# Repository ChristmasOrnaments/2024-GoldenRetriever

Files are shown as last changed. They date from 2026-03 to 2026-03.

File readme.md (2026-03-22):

Christmas ornament number 12...

***

The detailed explanation of the original Snowman ornament is [here](https://github.com/ChristmasOrnaments/2013-Snowman).

This ornament shares the same schematic and code base as the previous ornaments. Obviously the silkscreen image and LED locations have changed.  

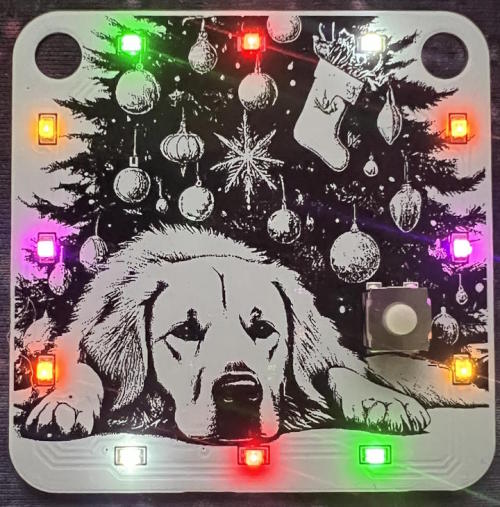
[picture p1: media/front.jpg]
front

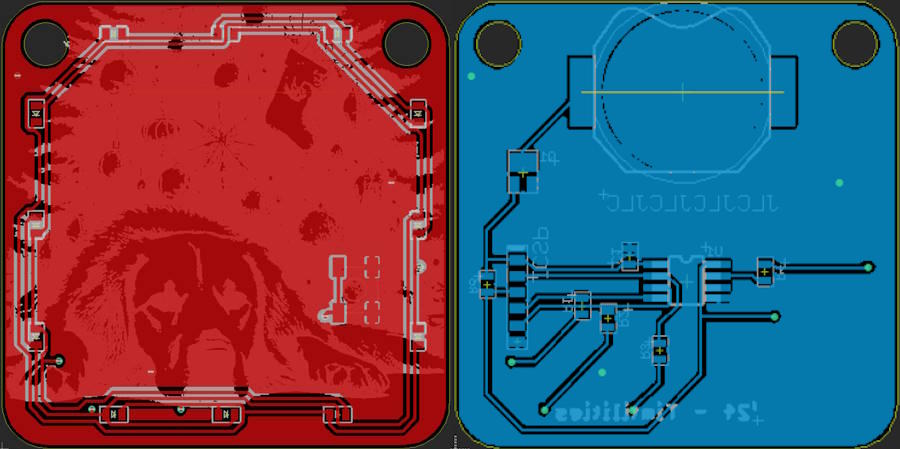
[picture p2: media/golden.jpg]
goldenretriever

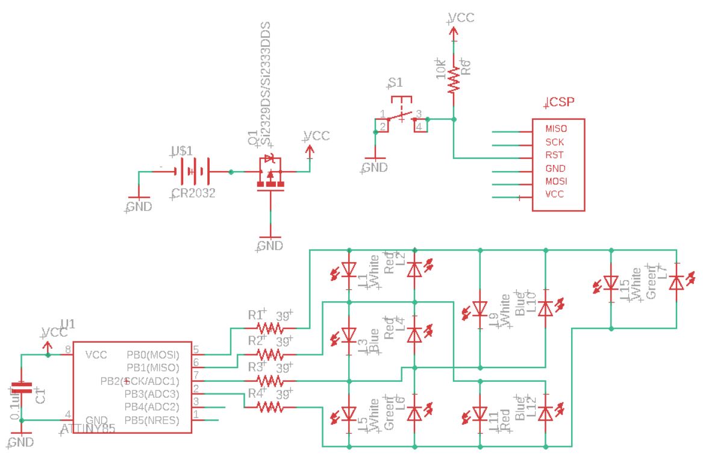
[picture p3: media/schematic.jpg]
schematic

GoldenRetriever

### Compiling

* Install [ATTinyCore](https://github.com/spencekonde/attinycore) using the boards manager
* Select **Attiny25/45/85 (No bootloader)** from the boards list
* Set the *Clock source* to **8MHz (internal)** (Code uses a prescalar of 2 to lower it to 4MHz)
* Set *B.O.D* to **Disabled**
* Select **Burn Bootloader** to write the changes
* Compile and write the program to the MCU

If using another method to program the MCU, just remember you need to set the fuses properly both for correct speed and for the power saving features. The fuses (for an ATTINY85) should be:

Low: 62  
High: DF  
Extended: FF

You can see the effect of different fuse settings (and their values) [here](http://www.engbedded.com/fusecalc/).

### Resources

**Charlieplexing Code using a byte array:**  
[https://www.instructables.com/CharliePlexed-LED-string-for-the-Arduino/](https://www.instructables.com/CharliePlexed-LED-string-for-the-Arduino/)

**Battery calculator:**  
[http://oregonembedded.com/batterycalc.htm](http://oregonembedded.com/batterycalc.htm)

**Power saving information:**  
[http://www.gammon.com.au/forum/?id=11497](http://www.gammon.com.au/forum/?id=11497)  
[http://www.insidegadgets.com/2011/02/05/reduce-attiny-power-consumption-by-sleeping-with-the-watchdog-timer](http://www.insidegadgets.com/2011/02/05/reduce-attiny-power-consumption-by-sleeping-with-the-watchdog-timer/)  
[http://www.nongnu.org/avr-libc/user-manual/group\_\_avr\_\_power.html](http://www.nongnu.org/avr-libc/user-manual/group__avr__power.html)

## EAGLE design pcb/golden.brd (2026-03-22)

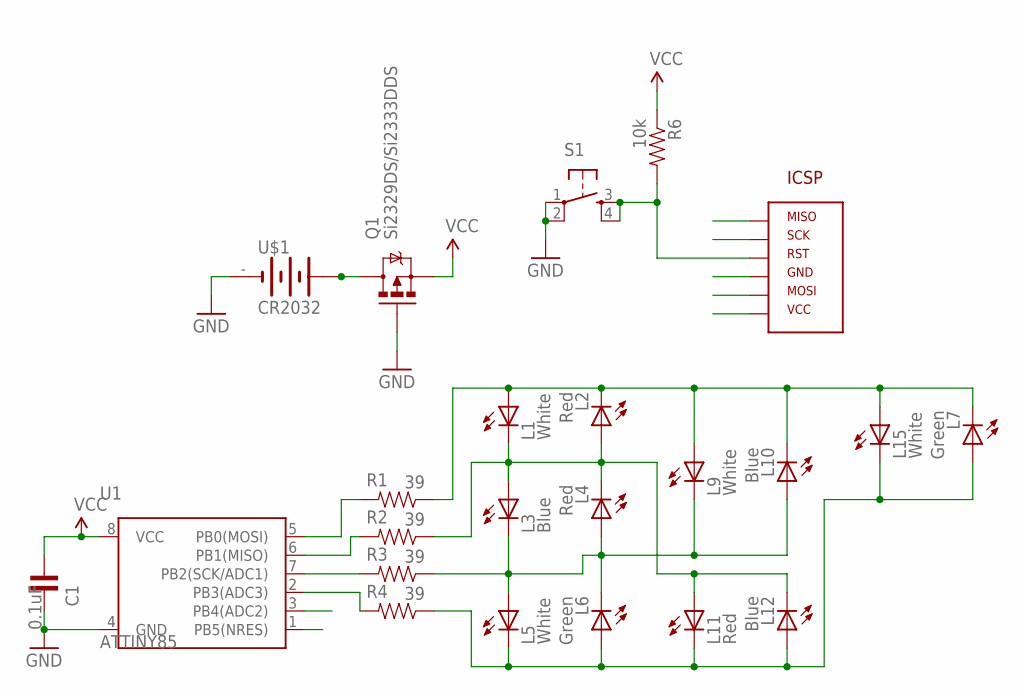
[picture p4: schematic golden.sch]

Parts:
C1: 0.1uF; C0805
L1, L5, L9, L15: White; LED-0805
L2, L4, L11: Red; LED-0805
L3, L10, L12: Blue; LED-0805
L6, L7: Green; LED-0805
Q1: Si2329DS/Si2333DDS; SOT23-3A
R1, R2, R3, R4: 39; R0805
R6: 10k; R0805
S1: TAC_SWITCHSMD; TACTILE_SWITCH_SMD
U1: ATTINY85; SOIC-8
U$1: CR2032; BAT-HLD-001
U$2: AVR_ICSP_6P1X6; AVR_ICSP_1X6_SMD

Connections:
GND: C1.2, Q1.1 (G), S1.1, S1.2, U1.4 (GND), U$1.-, U$2.P6 (GND)
L12: L1.C, L2.A, L3.A, L4.C, L11.A, L12.C, R2.1
MISO: R2.2, U1.6 (PB1(MISO)), U$2.P5 (MISO)
MOSI: R1.2, U1.5 (PB0(MOSI)), U$2.P4 (MOSI)
unnamed: Q1.3 (D), U$1.+@1 (+), U$1.+@2 (+)
unnamed: L3.C, L4.A, L5.A, L6.C, L9.C, L10.A, R3.1
unnamed: R4.2, U1.2 (PB3(ADC3))
unnamed: L1.A, L2.C, L7.C, L9.A, L10.C, L15.A, R1.1
unnamed: L5.C, L6.A, L7.A, L11.C, L12.A, L15.C, R4.1
RST: R6.2, S1.3, S1.4, U1.1 (PB5(NRES)), U$2.P3 (RST)
SCK: R3.2, U1.7 (PB2(SCK/ADC1)), U$2.P2 (SCK)
VCC: C1.1, Q1.2 (S), R6.1, U1.8 (VCC), U$2.P1 (VCC)

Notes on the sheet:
ICSP

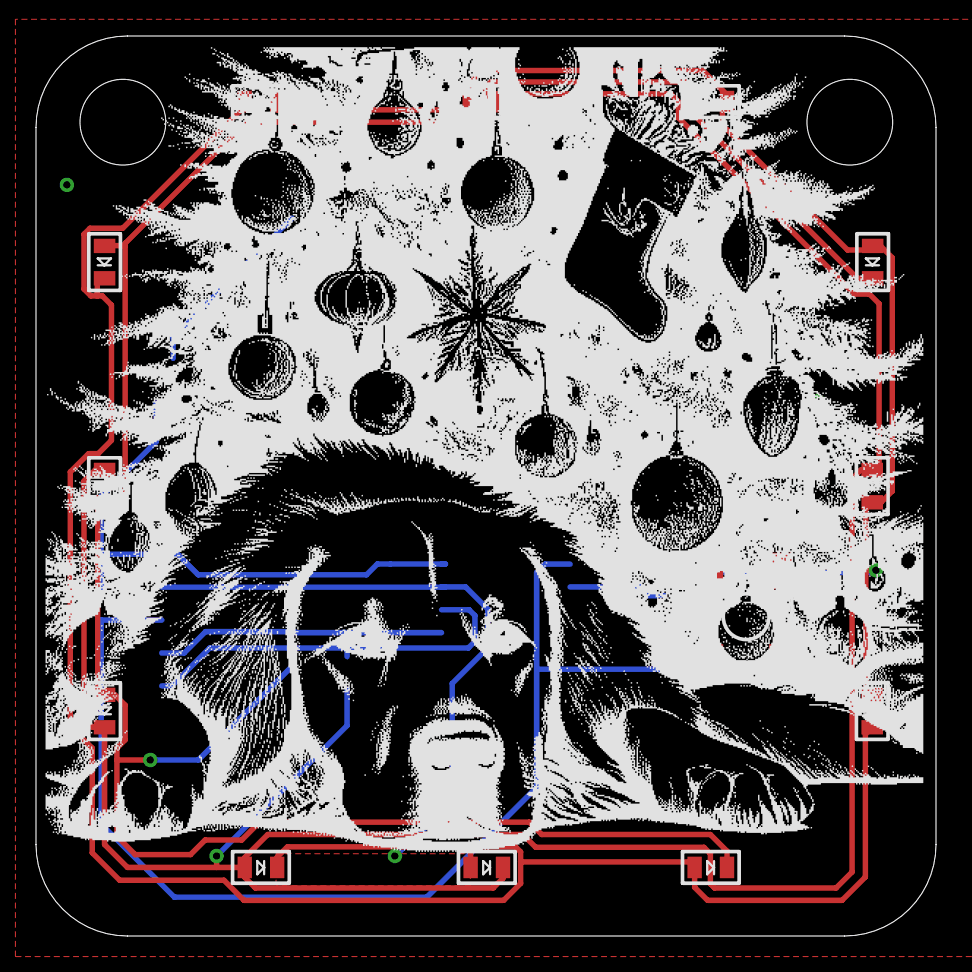
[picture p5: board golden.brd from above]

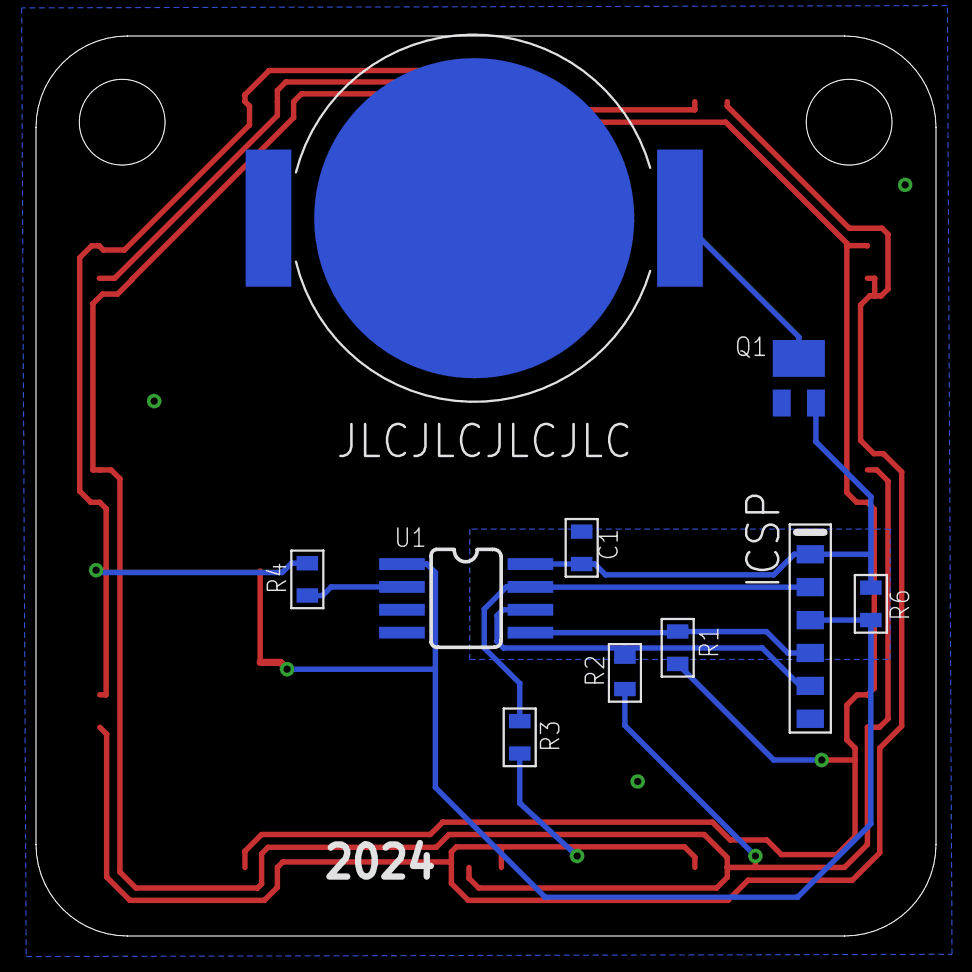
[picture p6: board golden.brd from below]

Board: 2 copper layers, 50.0 x 50.0 mm, 23 parts (10 on the bottom side), 12 nets.

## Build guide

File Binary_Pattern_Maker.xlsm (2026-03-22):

 |  |  |  |  |  |  | Not Used
 |  |  | 0 | 0 | 0
 | 0 |  |  |  |  | 0
 | 0 |  |  |  |  | 0
 | 0 |  |  |  |  | 0
 |  |  | 0 | 0 | 0
9-LED Array: |  | 0,0,0,0,0,0,0,0,0
12-LED Array: |  | 0,0,0,0,0,0,0,0,0,0,0,0

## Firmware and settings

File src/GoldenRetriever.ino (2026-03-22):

/*
 * ATTiny85_Internal_8MHz_Template.cpp
 *
 * Created: 11/5/2024
 * Charlieplexing functions modeled after the code found here:
 *  http://www.instructables.com/id/CharliePlexed-LED-string-for-the-Arduino/step7/Coding-the-Arduino/
 * 2019 - Added prescalar of 2 to accomodate 8MHz clock div/8 (low fuse 0x62)
 */ 

#ifdef F_CPU  
#undef F_CPU
#endif	
#define F_CPU 4000000 // 4 MHz

// ATMEL ATTINY85 / ARDUINO
//	            						  ____
//  		   (D5/A0) RST/PB5	1|*	  |8  VCC
//	 PWM   (D3/A3)	   PB3	2|	  |7  PB2  (D2/A1)
//	 PWM   (D4/A2)	   PB4	3|	  |6  PB1  (D1)		PWM
//	        				   GND	4|____|5  PB0  (D0)		PWM

#include <avr/pgmspace.h>
// Power Mgt:
#include <avr/sleep.h>
#include <avr/wdt.h>

// FUNCTION PROTOTYPES
void displayChar(int from, int through, int tranSpeed); // loads a Pattern from above. From & through specify what patterns to show. tranSpeed is the speed of the frames
//void ledSpecify(int highPin, int lowPin); // This allows you to manually control which pin goes low & which one goes high
void turnon(int led); // This turns on a certian led from the list of leds
void alloff(); // This turns all the LED's off
void setup_watchdog(int ii);
void system_sleep();

// ******************************************************************************************************************
//
// Much of the charlieplex code has been modified from http://www.instructables.com/id/CharliePlexed-LED-string-for-the-Arduino/step7/Coding-the-Arduino/
// The power management code is from 

#define LEDCount 12
byte pins[4];
//const byte LEDCount = 20;

// The attiny85 watchdog only sleeps for 8 seconds at a time, so for a longer period of time we need to setup a counter variable
//	 and check that against the # of times it wakes up.
// The internal clock isn't very accurate, so you need to factor that in. My tests show a deviation of ~0.9198 at 900 seconds,
//	 so a rough equation would be [ SleepTime = DesiredTime * 0.9198 ]
// Every MCU will be different, so some experimentation will be necessary if you want accurate intervals
// Some example times:
//	 5:00 -> 276
//	10:00 -> 552
//	15:00 -> 828
//	30:00 -> 1656
int SleepTime = 416; // Sleep time in seconds

int SleepCnt = SleepTime/8; // counter for watchdog wake timer

// blinkdelay is used by displayChar to set the microseconds the LED will be on, then off. It can affect brightness, but mostly affects speed
// blinkdelay could be replaced with a timeOn and timeOff to facilitate a type of PWM to increase LED brightness at low voltage 
//		(using a small Rs at higher voltage would be bad for LED unless turn-on time can be limited with this)
int blinkdelay = 90;   //Speed Param 1: smaller = faster
// runSpeed is the number of times displayChar will loop through each pattern before going to the next. Again, this affects speed
byte runSpeed = 90;		 //Speed Param 2: smaller = faster (0-255) - this can be set individually when calling displayChar()

// Random number
int RndNumber = 0;

#ifndef cbi
#define cbi(sfr, bit) (_SFR_BYTE(sfr) &= ~_BV(bit))
#endif
#ifndef sbi
#define sbi(sfr, bit) (_SFR_BYTE(sfr) |= _BV(bit))
#endif
volatile boolean f_wdt = 1;

const byte LEDConnections[LEDCount][2] ={	// This stores which outputs the LEDs are connected to: { Anode, Cathode }
	// Bottom Row
	{ 0 , 1 },	  //X1
	{ 1 , 2 },	  //X3
	{ 2 , 3 },	  //X5
	// Row 1
	{ 1 , 0 },	  //X2			  
	{ 2 , 1 },	  //X4
	{ 3 , 2 },	  //X6
	// Row 2
	{ 0 , 2 },	  //X9
	{ 1 , 3 },	  //X11
	// Row 3
	{ 2 , 0 },	  //X10
	{ 3 , 1 },	  //X12
	// Row 4
	{ 0 , 3 },	  //X15
	{ 3 , 0 }	  //X7
};

const byte displays[][LEDCount] PROGMEM ={	// This stores the array in Flash ROM.
	// All Off (0)
	{0,0,0,0,0,0,0,0,0,0,0,0},

	// Pattern 1: All LEDs Flash (1-2)
	{1,1,1,1,1,1,1,1,1,1,1,1},
	{0,0,0,0,0,0,0,0,0,0,0,0},

	// Pattern 2: 3 LED Race Clockwise (3-28)
	{ 0,0,1,0,0,0,0,0,0,0,0,0 }, //  3 x
	{ 0,0,1,0,0,0,0,0,0,1,0,0 }, //  4 xx
	{ 0,0,1,0,0,0,0,0,0,1,1,0 }, //  5 xxx
	{ 0,0,0,0,0,0,0,0,0,1,1,1 }, //  6  xxx
	{ 0,0,0,0,0,0,0,1,0,0,1,1 }, //  7   xxx
	{ 0,0,0,0,0,1,0,1,0,0,0,1 }, //  8    xxx
	{ 0,0,0,0,0,1,0,1,1,0,0,0 }, //  9     xxx
	{ 0,0,0,0,1,1,0,0,1,0,0,0 }, // 10      xxx
	{ 0,1,0,0,1,0,0,0,1,0,0,0 }, // 11       xxx
	{ 1,1,0,0,1,0,0,0,0,0,0,0 }, // 12        xxx
	{ 1,1,0,1,0,0,0,0,0,0,0,0 }, // 13         xxx
	{ 1,0,0,1,0,0,1,0,0,0,0,0 }, // 14          xxx
	{ 0,0,1,1,0,0,1,0,0,0,0,0 }, // 15 x         xx
	{ 0,0,1,0,0,0,1,0,0,1,0,0 }, // 16 xx         x
 
	{ 0,0,1,0,0,0,0,0,0,1,1,0 }, // 17 xxx -
	{ 0,0,0,0,0,0,0,0,0,1,1,1 }, // 18  xxx -
	{ 0,0,0,0,0,0,0,1,0,0,1,1 }, // 19   xxx -
	{ 0,0,0,0,0,1,0,1,0,0,0,1 }, // 20    xxx -
	{ 0,0,0,0,0,1,0,1,1,0,0,0 }, // 21     xxx -
	{ 0,0,0,0,1,1,0,0,1,0,0,0 }, // 22      xxx -
	{ 0,1,0,0,1,0,0,0,1,0,0,0 }, // 23       xxx -
	{ 1,1,0,0,1,0,0,0,0,0,0,0 }, // 24        xxx -
	{ 1,1,0,1,0,0,0,0,0,0,0,0 }, // 25         xxx -
	{ 1,0,0,1,0,0,1,0,0,0,0,0 }, // 26          xxx -
 
	{ 0,0,0,1,0,0,1,0,0,0,0,0 }, // 27           xx
	{ 0,0,0,0,0,0,1,0,0,0,0,0 }, // 28            x

	// Pattern 3: "+" rotation (29-40)
	{ 1,0,1,0,0,0,0,0,1,0,0,1 },
	{ 0,0,0,1,1,0,0,1,0,1,0,0 },
	{ 0,1,0,0,0,1,1,0,0,0,1,0 },
	{ 1,0,1,0,0,0,0,0,1,0,0,1 },
	{ 0,0,0,1,1,0,0,1,0,1,0,0 },
	{ 0,1,0,0,0,1,1,0,0,0,1,0 },
	{ 1,0,1,0,0,0,0,0,1,0,0,1 },
	{ 0,0,0,1,1,0,0,1,0,1,0,0 },
	{ 0,1,0,0,0,1,1,0,0,0,1,0 },
	{ 1,0,1,0,0,0,0,0,1,0,0,1 },
	{ 0,0,0,1,1,0,0,1,0,1,0,0 },
	{ 0,1,0,0,0,1,1,0,0,0,1,0 },

	// Pattern 4: 2 LEDs Racing back and forth (41-46)
	{ 0,0,0,1,0,0,0,1,0,0,0,0 },
	{ 1,0,0,0,0,1,1,0,0,0,0,1 },
	{ 0,1,1,0,0,0,0,0,1,0,1,0 },
	{ 0,0,0,0,1,0,0,0,0,1,0,0 },
	{ 0,1,1,0,0,0,0,0,1,0,1,0 },
	{ 1,0,0,0,0,1,1,0,0,0,0,1 },

	// Pattern 5: 2 LEDs race from top-left corner to bottom-right corner and back (47-65)
	{ 0,0,1,0,0,0,0,0,0,0,0,0 },
	{ 0,0,0,0,0,0,1,0,0,1,0,0 },
	{ 0,0,0,1,0,0,0,0,0,0,1,0 },
	{ 1,0,0,0,0,0,0,0,0,0,0,1 },
	{ 0,1,0,0,0,0,0,1,0,0,0,0 },
	{ 0,0,0,0,1,1,0,0,0,0,0,0 },
	{ 0,0,0,0,0,0,0,0,1,0,0,0 },
	{ 0,0,0,0,1,1,0,0,0,0,0,0 },
	{ 0,1,0,0,0,0,0,1,0,0,0,0 },
	{ 1,0,0,0,0,0,0,0,0,0,0,1 },
	{ 0,0,0,1,0,0,0,0,0,0,1,0 },
	{ 0,0,0,0,0,0,1,0,0,1,0,0 }, // line 58
	{ 0,0,1,0,0,0,0,0,0,0,0,0 },
	{ 0,0,0,0,0,0,1,0,0,1,0,0 },
	{ 0,0,0,1,0,0,0,0,0,0,1,0 },
	{ 1,0,0,0,0,0,0,0,0,0,0,1 },
	{ 0,1,0,0,0,0,0,1,0,0,0,0 },
	{ 0,0,0,0,1,1,0,0,0,0,0,0 },
	{ 0,0,0,0,0,0,0,0,1,0,0,0 },

	// Pattern 6: 3 LED Race Counter-Clockwise (66-91) 
	{ 0,0,0,0,0,0,1,0,0,0,0,0 },
	{ 0,0,0,1,0,0,1,0,0,0,0,0 },
	{ 1,0,0,1,0,0,1,0,0,0,0,0 },
	{ 1,1,0,1,0,0,0,0,0,0,0,0 },
	{ 1,1,0,0,1,0,0,0,0,0,0,0 },
	{ 0,1,0,0,1,0,0,0,1,0,0,0 },
	{ 0,0,0,0,1,1,0,0,1,0,0,0 },
	{ 0,0,0,0,0,1,0,1,1,0,0,0 },
	{ 0,0,0,0,0,1,0,1,0,0,0,1 },
	{ 0,0,0,0,0,0,0,1,0,0,1,1 },
	{ 0,0,0,0,0,0,0,0,0,1,1,1 },
	{ 0,0,1,0,0,0,0,0,0,1,1,0 },
	{ 0,0,1,0,0,0,1,0,0,1,0,0 },
	{ 0,0,1,1,0,0,1,0,0,0,0,0 },
	{ 1,0,0,1,0,0,1,0,0,0,0,0 },
	{ 1,1,0,1,0,0,0,0,0,0,0,0 },
	{ 1,1,0,0,1,0,0,0,0,0,0,0 },
	{ 0,1,0,0,1,0,0,0,1,0,0,0 },
	{ 0,0,0,0,1,1,0,0,1,0,0,0 },
	{ 0,0,0,0,0,1,0,1,1,0,0,0 },
	{ 0,0,0,0,0,1,0,1,0,0,0,1 },
	{ 0,0,0,0,0,0,0,1,0,0,1,1 },
	{ 0,0,0,0,0,0,0,0,0,1,1,1 },
	{ 0,0,1,0,0,0,0,0,0,1,1,0 },
	{ 0,0,1,0,0,0,0,0,0,1,0,0 },
	{ 0,0,1,0,0,0,0,0,0,0,0,0 }, 

	// Pattern 7: Twinkle (92-101)
/*	{ 0,0,0,0,0,0,1,0,0,0,0,0 },
	{ 1,0,0,0,0,0,0,0,0,0,1,0 },
	{ 0,0,0,0,1,1,1,0,0,0,0,0 },
	{ 0,1,0,0,0,0,0,0,0,1,0,0 },
	{ 1,0,1,0,0,1,0,0,0,0,0,0 },
	{ 0,0,0,0,0,0,0,0,0,0,0,1 },
	{ 0,0,0,0,0,0,1,0,1,1,0,0 },
	{ 1,0,1,0,0,0,0,0,0,0,0,0 },
	{ 0,0,1,0,1,0,0,0,0,0,1,0 },
	{ 0,0,0,0,0,0,0,0,1,0,0,0 },	*/

	// Pattern 8: LEDs race from L12 to L4 in opposite directions (102-114)
	{ 0,0,0,0,0,0,0,0,0,1,0,0 },
	{ 0,0,1,0,0,0,0,0,0,0,1,0 },
	{ 0,0,0,0,0,0,1,0,0,0,0,1 },
	{ 0,0,0,1,0,0,0,1,0,0,0,0 },
	{ 1,0,0,0,0,1,0,0,0,0,0,0 },
	{ 0,1,0,0,0,0,0,0,1,0,0,0 },
	{ 0,0,0,0,1,0,0,0,0,0,0,0 },

	{ 0,1,0,0,0,0,0,0,1,0,0,0 },
	{ 1,0,0,0,0,1,0,0,0,0,0,0 },
	{ 0,0,0,1,0,0,0,1,0,0,0,0 },
	{ 0,0,0,0,0,0,1,0,0,0,0,1 },
	{ 0,0,1,0,0,0,0,0,0,0,1,0 },
	{ 0,0,0,0,0,0,0,0,0,1,0,0 },

};

void setup()   {
	// Set prescalar so the clock runs at 4MHz
	// See here: https://forum.arduino.cc/index.php?topic=624890.0
	cli(); //disable interrupts - this is a timed sequence.
	CLKPR=0x80; //change enable
	CLKPR=0x01; //set prescaler to 2
	sei(); //enable interrupts
  
	// initialize the digital pin as an output:
	pins[0] = 0;
	pins[1] = 1;
	pins[2] = 2;
	pins[3] = 3;

	// Status LED
	//pinMode(4, OUTPUT);

	setup_watchdog(9); // Watchdog timer; approximately 8 seconds sleep
	randomSeed(analogRead(A2));	 // Seeds the random number generator for more randomness. A2 must be disconnected!
}

void loop()						
{
	int PastRnd = 0;
	if (f_wdt==1) {	 // wait for timed out watchdog / flag is set when a watchdog timeout occurs

		f_wdt=0;	   // reset flag
		if (SleepCnt >= (SleepTime/8)) {
			SleepCnt = 0; // Reset sleep counter
			// Code to execute after we wake from sleep:		  
			// displayChar( from, through, tranSpeed )
			for (int demos=0; demos<3; demos++) {
				// Generate a random number for pattern selection
				while (RndNumber == PastRnd) { RndNumber = random(1,9); }
				PastRnd = RndNumber;
				switch (RndNumber) {
				case 1: // Pattern 2  
					//displayChar(3,28, 70);
          //displayChar(3,28, 70); 
          displayChar(3,4, 70);
          displayChar(5,17, 70);
          for (int loop=0; loop<2; loop++) {
            displayChar(6,17, 70);
          }
          displayChar(6,14, 70);
          displayChar(27,28, 70);
					break;
				case 2: // Pattern 3  
					for (int loop=0; loop<2; loop++) {
					  displayChar(29,40, 70); 
					}							   
					break;
				case 3: // Pattern 4  
					for (int loop=0; loop<2; loop++) {
						  displayChar(41, 46, 70);
              displayChar(41, 46, 70);
              displayChar(41, 46, 70);
					}
					displayChar(41, 41, 70);
					break;			  
				case 4: // Pattern 1 - Blink them all  
					for (int loop=0; loop<4; loop++) {
						displayChar(0, 0, 210);
						delay(50);
						displayChar(1, 1, 210); 
						delay(150);
					}
					break;	   
				case 5: // Pattern 5  
					//for (int loop=0; loop<2; loop++) {
					//displayChar(47, 65, 70); 
          //displayChar(47, 65, 70);
          for (int loop=0; loop<4; loop++) {
            displayChar(47, 58, 70);
          }
          displayChar(47, 47, 70);
					break;
				case 6: // Pattern 6  
					displayChar( 66, 91, 70);
          displayChar( 66, 91, 70); 
					break;									  
/*				case 7: // Pattern 7  
					for (int loop=0; loop<3; loop++) {
					  displayChar( 92, 101, 100); 
					}							   
					break;		*/
				case 7: // Pattern 8  
					for (int loop=0; loop<4; loop++) {
					  //displayChar( 102, 114, 70); 
            displayChar( 92, 104, 70);
					}							   
					break;											
				}
			}
// End of wake code

			//pinMode(0,INPUT); // Normally you would set the pinMode to INPUT to save power, but since the charlieplexing code does this, we don't need to here
			system_sleep();
			//pinMode(0,OUTPUT); // Set the pinmode back to OUTPUT, as it was before	
		} else {
			SleepCnt++;
			//pinMode(0,INPUT); // Normally you would set the pinMode to INPUT to save power, but since the charlieplexing code does this, we don't need to here
			system_sleep();
			//pinMode(0,OUTPUT); // Set the pinmode back to OUTPUT, as it was before
		}
	}	
}

// Charlieplexing Code
// *********************************************************************************************

// Courtesy of "computergeek"
// http://www.instructables.com/id/CharliePlexed-LED-string-for-the-Arduino/step7/Coding-the-Arduino/
void displayChar(int from, int through, int tranSpeed)// loads a Pattern from above. From & through specify what patterns to show. tranSpeed is the speed of the frames (smaller=faster)
{
  boolean run = true;
  byte k;
  int t = from;
  while(run == true)
  {
	for(int i = 0; i < tranSpeed; i++)
	{
	  for(int j = 0; j < LEDCount; j++)
	  {
		  k = pgm_read_byte(&(displays[t][j]));
		  if (k == 2)
		  {
		    run = false;
		  }
		  else if(k == 1)
		  {
		    turnon(j);
		    delayMicroseconds(blinkdelay);
		    alloff();
		  }
		  else if(k == 0)
		  {
		    delayMicroseconds(blinkdelay);
		  }
	  }
	}
	if(through == t){
	  return;
	}
	t++;
  }
}

void turnon(int led) // This turns on a certian led from the list of leds
{
//	int pospin = LEDConnections[led][0] + 2;  //  <-- what is the +2 for?
//	int negpin = LEDConnections[led][1] + 2;
  int anode = LEDConnections[led][0];
  int cathode = LEDConnections[led][1];
  pinMode (anode, OUTPUT);
  digitalWrite (anode, HIGH);
  pinMode (cathode, OUTPUT);
  digitalWrite (cathode, LOW);
}

void alloff() // This turns all the LED's off
// TM - added sizeof(pins) to determine pin count (instead of hard-coded counts)
{
  for(int i = 0; i < sizeof(pins); i++)
  {
	pinMode (pins[i], INPUT);
  }
}

// Power Management
// *********************************************************************************************

// set system into the sleep state
// system wakes up when watchdog is timed out
void system_sleep() {
	cbi(ADCSRA,ADEN);					 // switch Analog to Digitalconverter OFF

	set_sleep_mode(SLEEP_MODE_PWR_DOWN); // sleep mode is set here
	sleep_enable();

	sleep_mode();						 // System sleeps here

	sleep_disable();					 // System continues execution here when watchdog timed out
	sbi(ADCSRA,ADEN);					 // switch Analog to Digitalconverter ON
}

// 0=16ms, 1=32ms,2=64ms,3=128ms,4=250ms,5=500ms
// 6=1 sec,7=2 sec, 8=4 sec, 9= 8sec
void setup_watchdog(int ii) {

	byte bb;
	int ww;
	if (ii > 9 ) ii=9;
	bb=ii & 7;
	if (ii > 7) bb|= (1<<5);
	bb|= (1<<WDCE);
	ww=bb;

	MCUSR &= ~(1<<WDRF);
	// start timed sequence
	WDTCR |= (1<<WDCE) | (1<<WDE);
	// set new watchdog timeout value
	WDTCR = bb;
	WDTCR |= _BV(WDIE);
}

// Watchdog Interrupt Service / is executed when watchdog timed out
ISR(WDT_vect) {
	f_wdt=1;  // set global flag
}

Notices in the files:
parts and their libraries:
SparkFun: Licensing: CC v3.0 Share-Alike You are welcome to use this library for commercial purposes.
